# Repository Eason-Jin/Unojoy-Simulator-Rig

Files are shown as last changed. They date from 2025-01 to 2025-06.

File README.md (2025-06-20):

# Unojoy-Simulator-Rig

This is a simple [Unojoy](https://github.com/AlanChatham/UnoJoy) controller I configured to play Euro Truck Simulator 2.

## Phase 1

A simple mockup of the controller with some off-the-shelf components, including push buttons, potentiometers, rotary encoders and switches. \
\
A picture of the mockup os shown below:
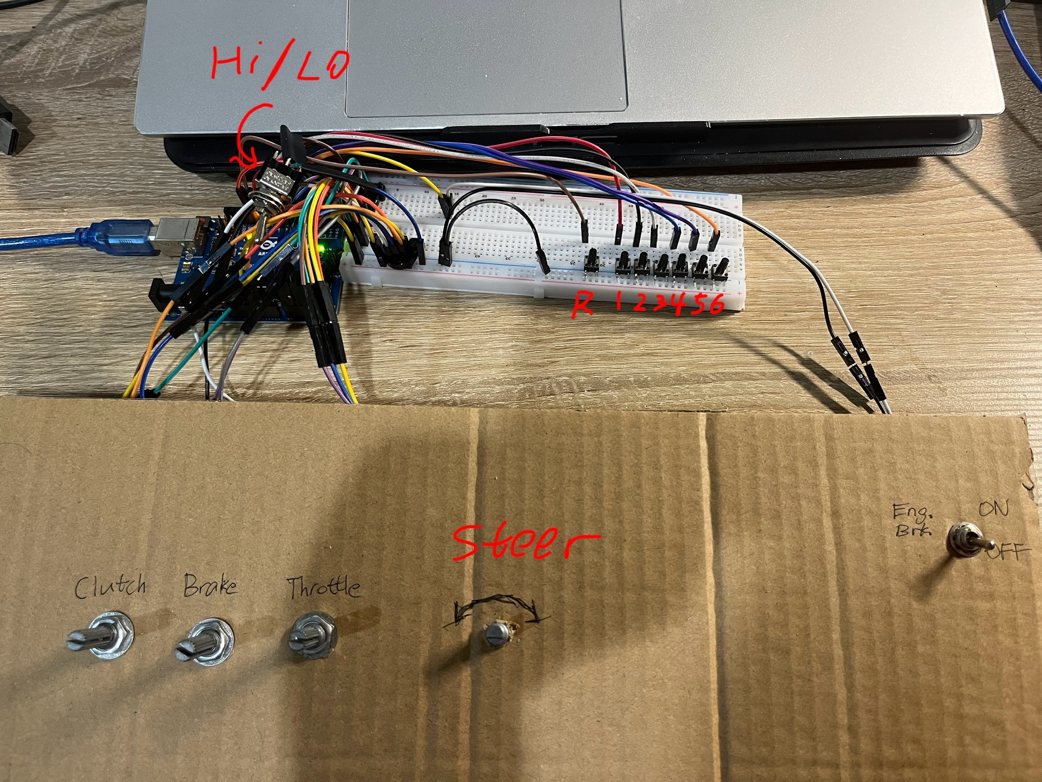
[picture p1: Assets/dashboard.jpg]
Mockup


The configration is as follows:

* 1 [Arduino Uno](https://surplustronics.co.nz/products/7014-arduino-uno-r3-clone-with-usb-cable).
* 1 [rotary encoder](https://surplustronics.co.nz/products/10776-rotary-encoder-module) for the steering wheel.
* 3 [potentiometers](https://surplustronics.co.nz/products/1686-10k-ohm-linear-potentiometer-) for the throttle, brake and clutch. Another one will be added later for the camera.
* 2 [toggle switches](https://surplustronics.co.nz/products/4314-switch-toggle-on-on-spdt-3-pins-panel-mount) as engine brake switch and high-low gear selector.
* 7 [tactile push buttons](https://surplustronics.co.nz/products/2159-switch-tact-push-button-momentary) for 6 forward gears and 1 reverse gear.

The wiring diagram is shown below:
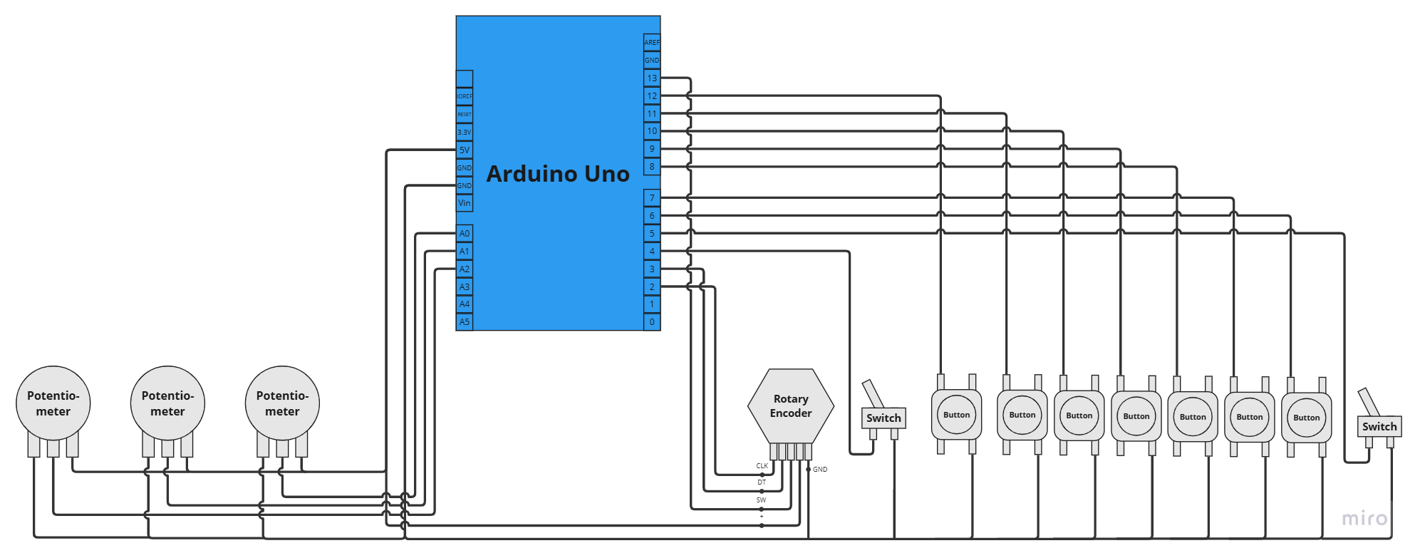
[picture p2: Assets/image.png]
Wiring diagram


Videos of the controller in action are under the `Assets` folder.

Shifting through a 12 speed with only hand controls is hard😅. So in phase 2 I will visit the near by wreckers to salvage some parts.

## Phase 2

### Acquiring Parts

I took the steering wheel out of a Mazda 323 (5th gen, BF). The 3D printed parts will adapt to this particlar steering wheel.

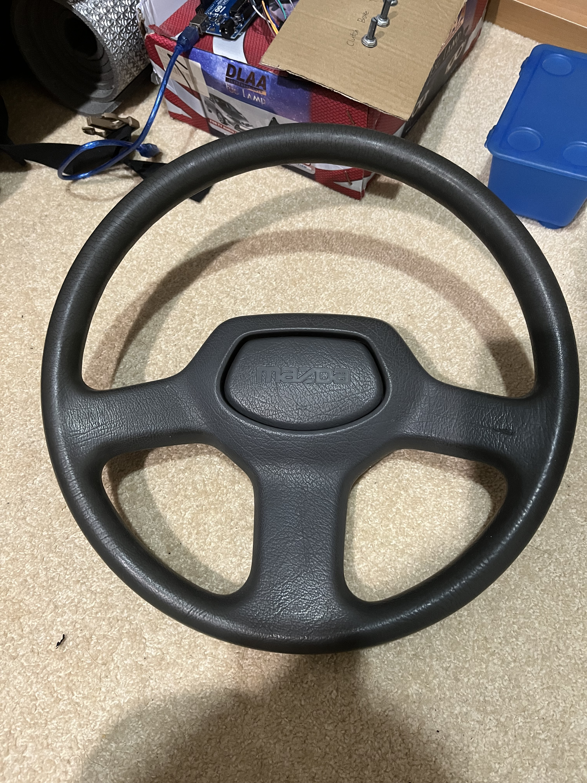
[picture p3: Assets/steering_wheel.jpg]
Steering Wheel


A picture of the car for reference (not this exact car):
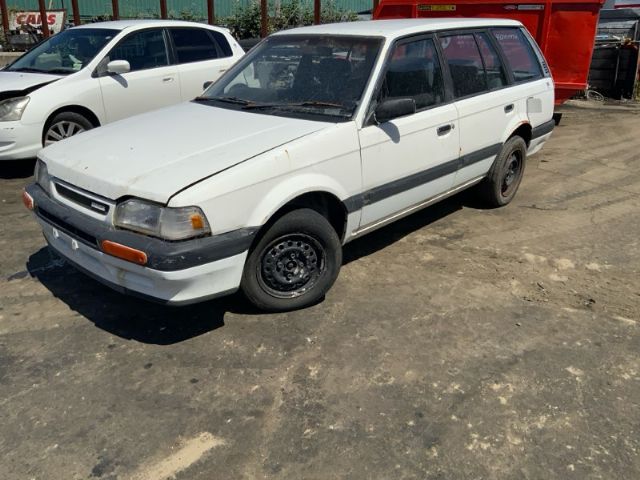
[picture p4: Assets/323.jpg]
Car


The seat is taken from the most luxurious car ever, the pinnicle of Australian engineering, the most beautiful curves human have ever crafted...

The AU Falcon Series II Wagon. (Image for illustration):
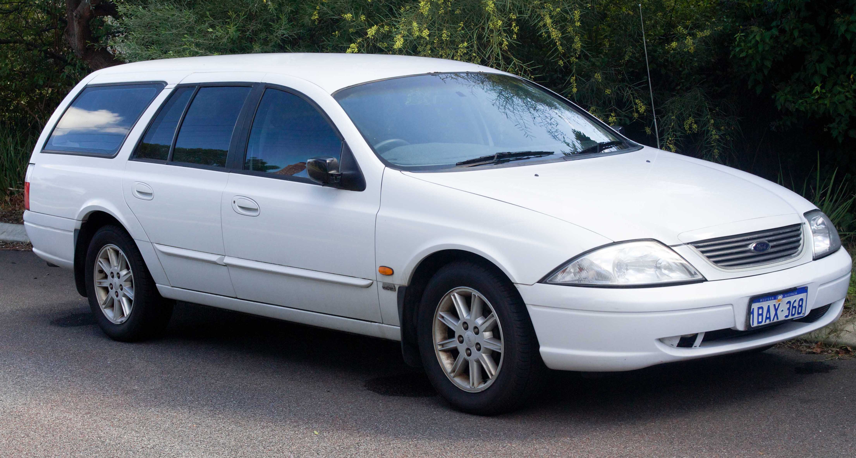
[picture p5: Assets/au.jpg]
AU Falcon


I will be constructing the rest of the simulator using 3D printed parts and off-the-shelf hardware. All CAD files are found under the `CAD` folder. CAD models are made with Autodesk Inventor.

### Steering Assembly

The steering wheel will be sandwiched between the grey and purple parts. The main steering shaft is a 32mm diameter PVC pipe. The steering wheel will be placed in between the silver and pink parts and held using a long M10 bolt for strength.

#### Front view

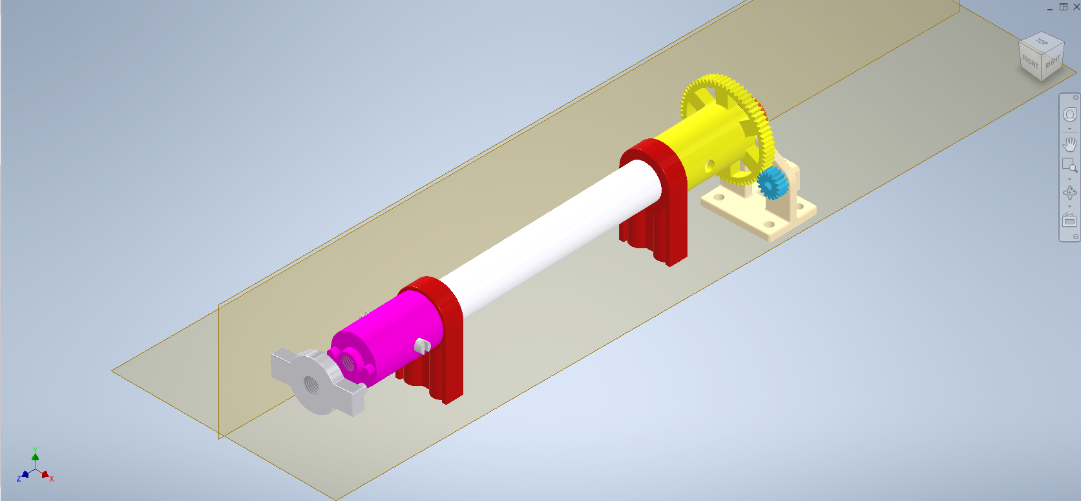
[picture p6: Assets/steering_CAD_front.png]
Steering front


#### Rear view

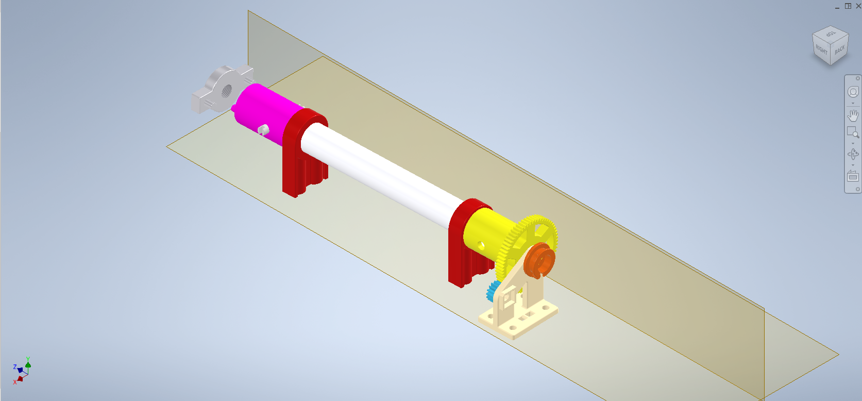
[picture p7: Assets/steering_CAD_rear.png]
Steering rear


A rubber band will be attached to the orange part behind the gear and goes to the support structure. This will provide auto-centering force. A proper force feedback motor is planned for the future.\
\
The cream support structure and the two red posts will be screwed to a wooden base plate with M6 screws.\
\
The encoder is a cheaper product, thus it only has 12 pulses per revolution. To counter that, a set of gears with ratio 16:64 to slightly increase the resolution. The encoder will go into the slot on the back of the cream support.

### Pedal Assembly

The three pedals will be revolving around the same 32mm PVC pipe. There is a hook on the green support and an ear on the grey pedals. A spring will be attached to the hook and the ear to provide resistance and resetting pedal positions. The potentiometers will be attached using a rope drive as shown in this [video](https://www.youtube.com/watch?v=5Pex7cJlhsA&list=WL&index=2&t=226s).

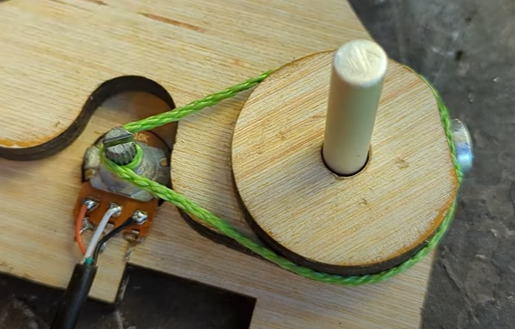
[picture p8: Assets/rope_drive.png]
Rope Drive


#### Front view

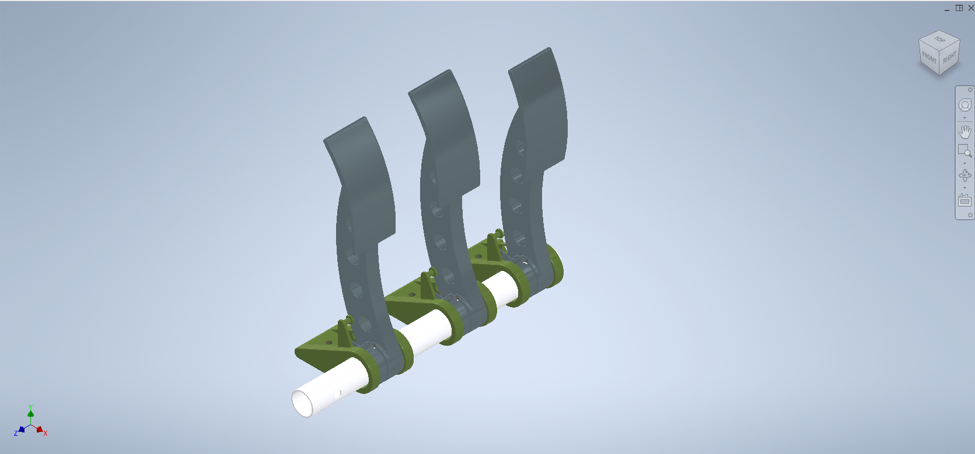
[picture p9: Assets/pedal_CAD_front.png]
Pedal Front


#### Rear view

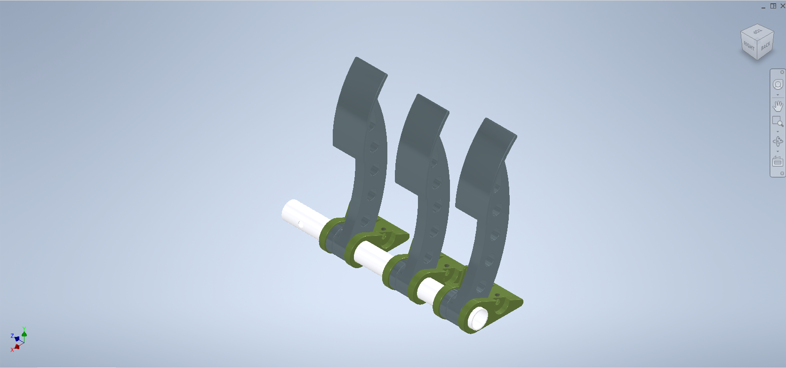
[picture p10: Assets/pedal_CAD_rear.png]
Pedal Rear


#### Pedal movement

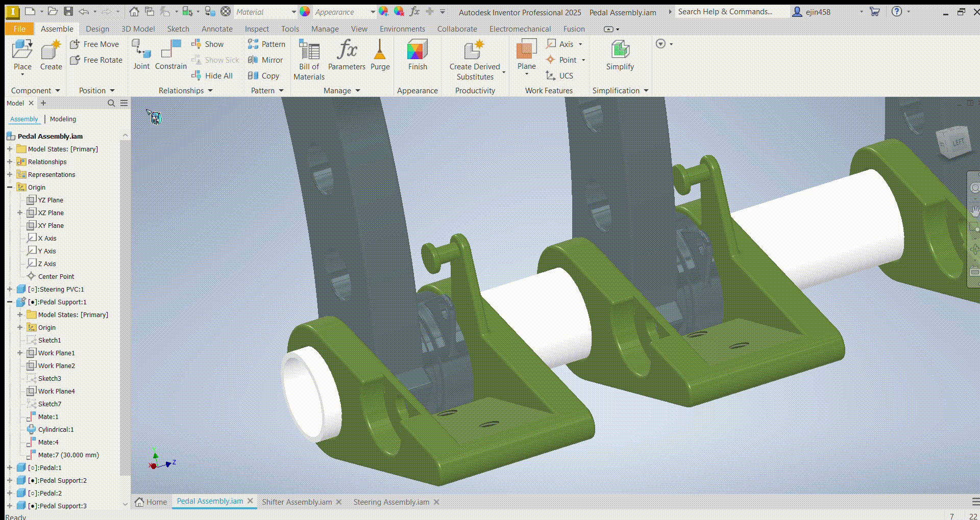
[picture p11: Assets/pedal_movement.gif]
Pedal Movement


Egonomics will be tested on these pedals to ensure comfort and ease of heel-and-toe shifting. The shape and size of the pedals may subject to change. (Or I might get some real pedals from a car, who knows?)

### Shifter Assembly

The shifter is a standard 6-speed H-pattern shifter with reverse next to 1st gear. The supporting columns and the actual shift rod are 15mm PVC pipes. One of the column needs to be removed to leave space for the reverse. However, considering they have very little load on them, this will not affect the stability of the shifter.

#### Front view

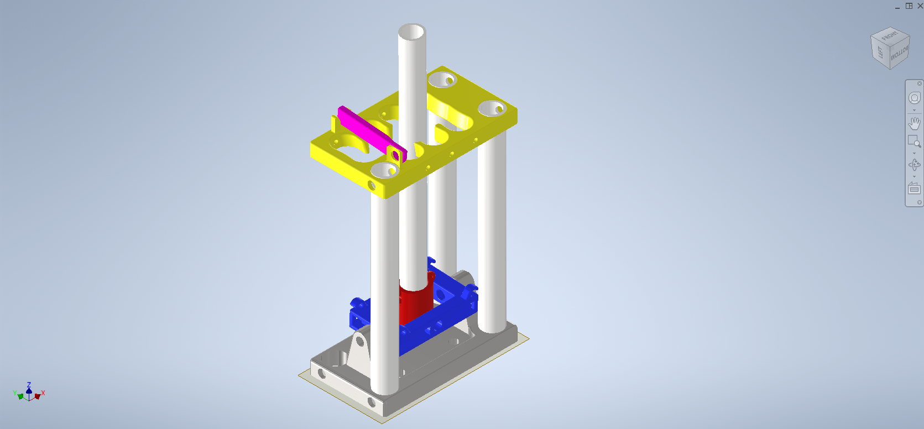
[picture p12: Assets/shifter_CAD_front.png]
Shifter Front


#### Rear view

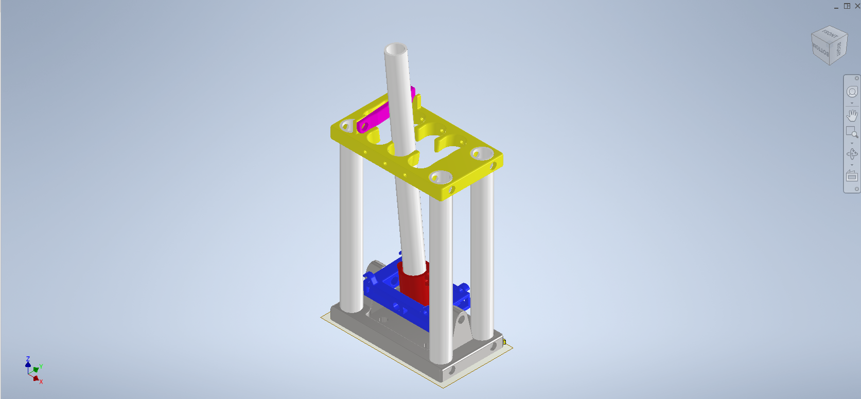
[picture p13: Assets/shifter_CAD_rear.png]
Shifter Rear


The purple piece is the reverse lockout, which can be flipped up for the shifter to move into reverse. This is inspired by the shifter in the [Ferrari 312 T2](https://www.youtube.com/watch?v=Ag03SegGTds). Jkjk 😁

| | |
| --- | --- |
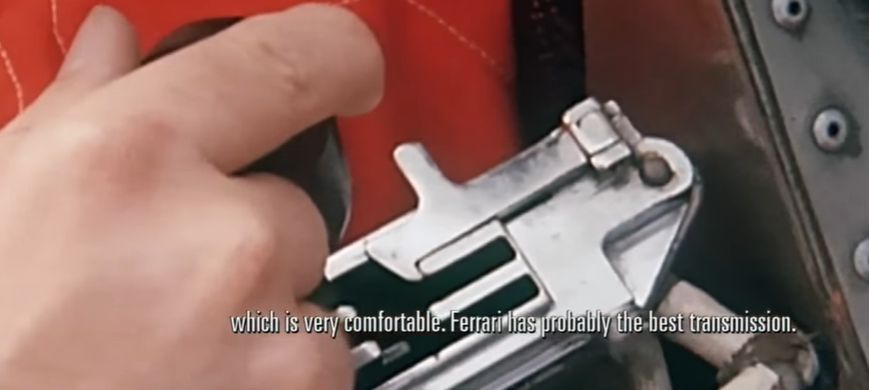
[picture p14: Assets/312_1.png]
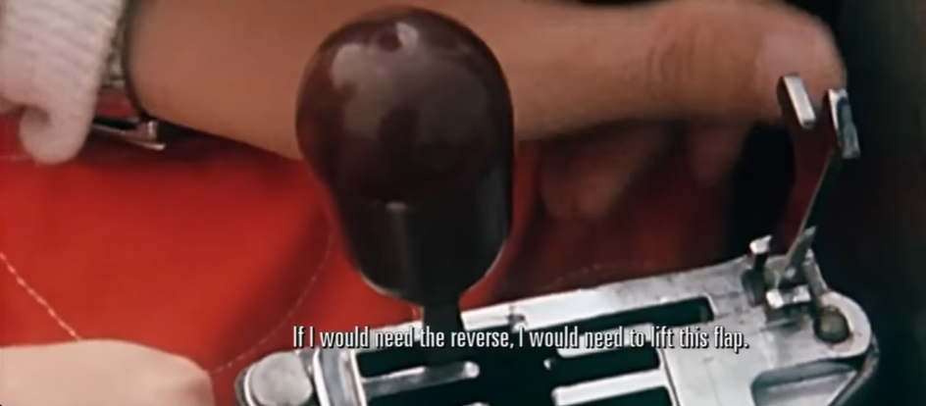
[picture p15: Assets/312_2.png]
|  |  |

#### Top view

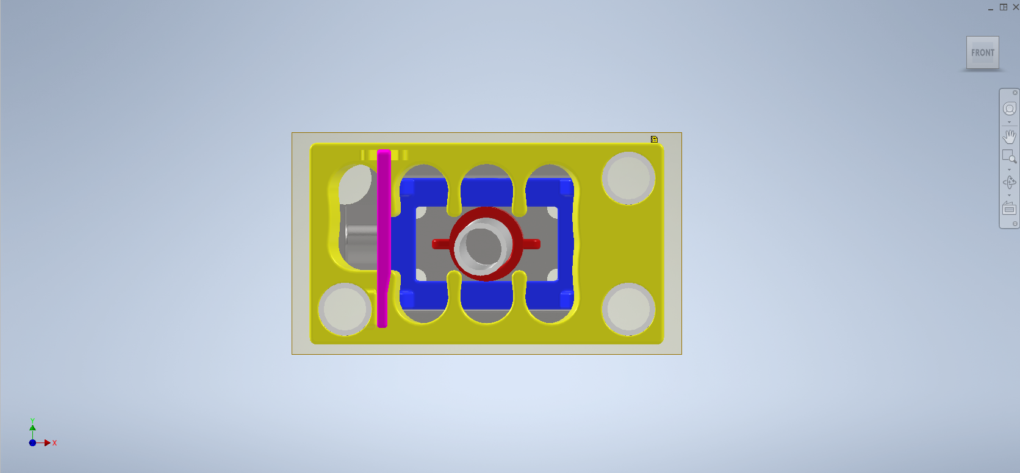
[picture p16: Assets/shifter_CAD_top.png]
Shifter Top


The tabs on the red part and the blue hooks are, again, for rubber bands for auto-centering horizontally (we keep this project low-budget💸). The slots that the shifter go in have a slightly narrow entrance, this allows the shifter to "pop" in place and stay there. \
\
There are holes on the side walls for the wire to run through. Another wire will run along the shift rod, when it moves into position, the wires will contact and complete the ciruit.

#### Shifter movement

Shifter Movement

Considering the amount of connections needed for shifter and gear knob alone, I might migrate some of the inputs to a second Arduino. This will also allow for more buttons and switches to be added in the future.

### Shift Knob

The shift knob is divided into 3 sections. The blue part has a switch poking out of it as the high/low range selector. The Orange part has a joystick to allow rotation of the camera. The grey part contains the potentiometer for the joystick.

#### Front view

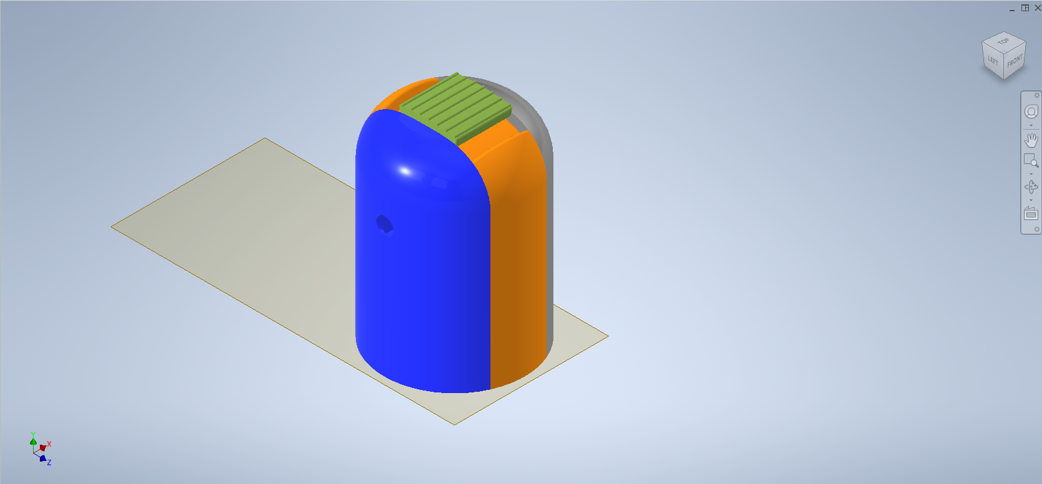
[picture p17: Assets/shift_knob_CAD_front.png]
Knob Front


#### Rear view

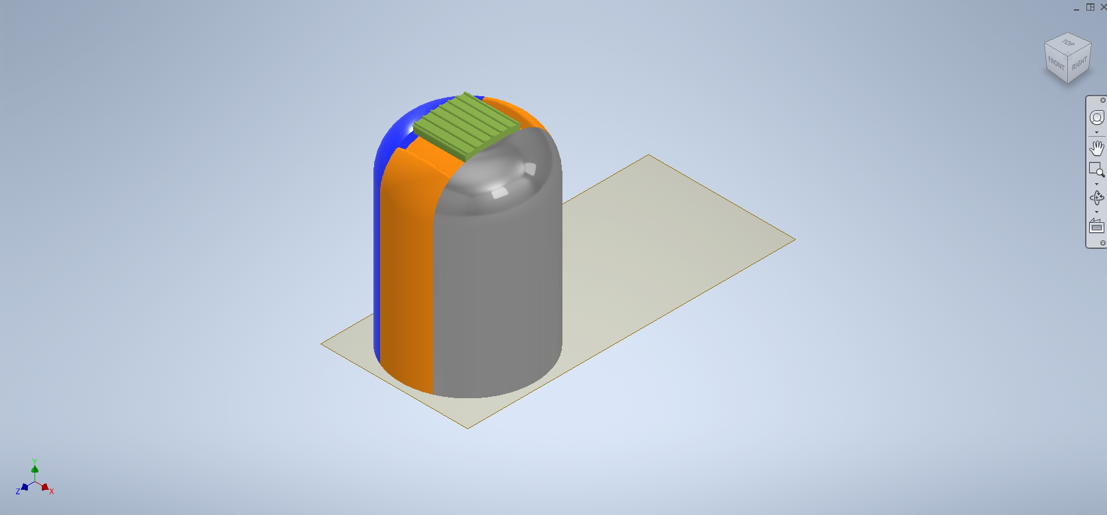
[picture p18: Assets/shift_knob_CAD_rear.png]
Knob Rear


#### Bottom view

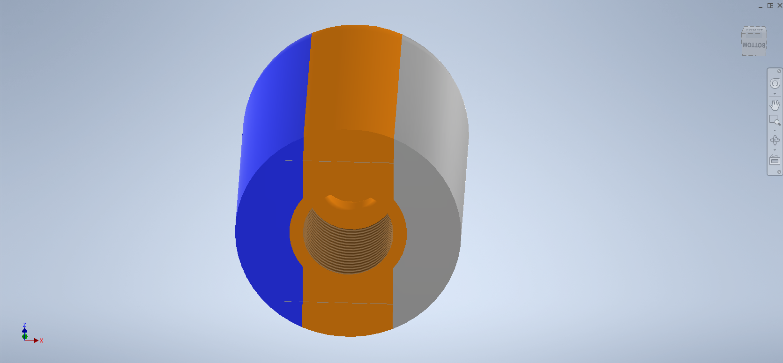
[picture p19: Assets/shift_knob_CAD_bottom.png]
Knob Bottom


The bottom of the shift knob is a M20 thread with a 12mm hole for the wires to run through.

#### Knob details

Knob Details

The joystick has a tab at the bottom, which allows rubber band to be attached on either side for auto-centering the camera. Due to the nature of Euro Trucks gameplay, vertical camera movement is not important.

## Phase 3

Various improvements were made along the way to the CAD models. Such as:

* The steering assembly was flipped upside-down so that it can be mounted on a angle without it being too high.
* The auto-centering rubber band was omitted because the wheel is simply too heavy for it to do anything (this issue should be solved with the introduction of a force-feedback motor in the future).
* The reverse lockout was omitted due to the lack of space.
* The pedals were shortened and mounted upside-down for a more natural feel.

Here are some angles of the complete construction:

| | |
| --- | --- |
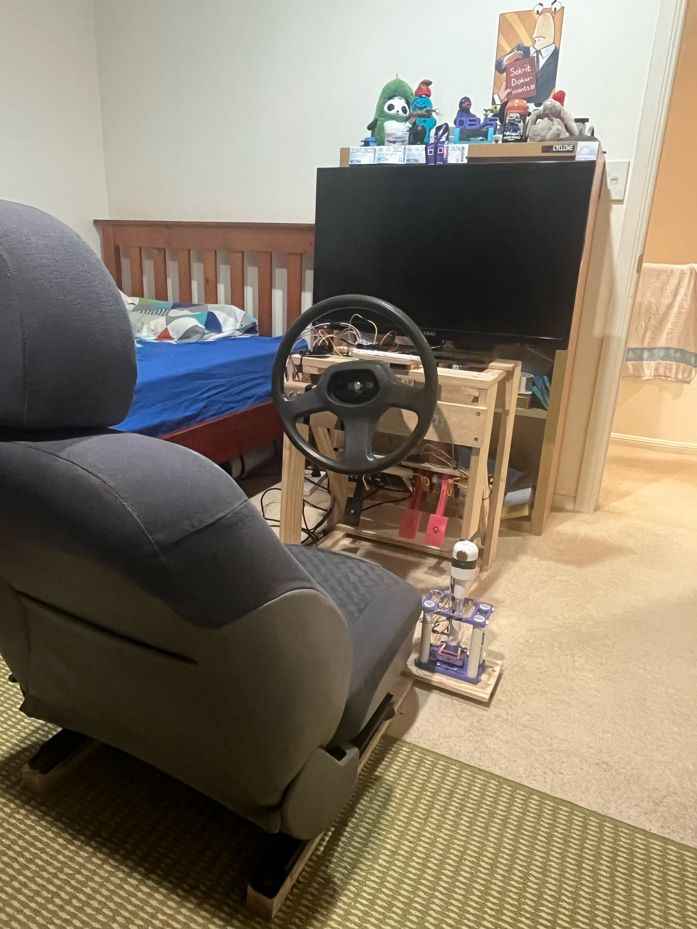
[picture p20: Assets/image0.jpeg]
Full
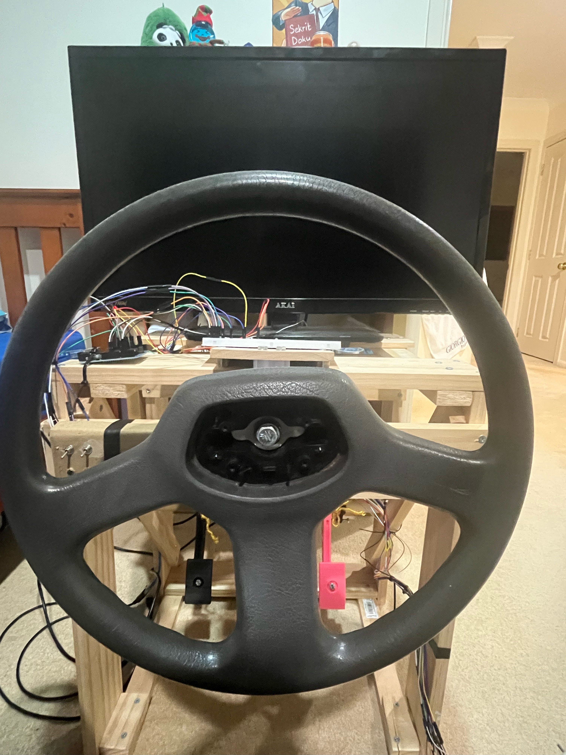
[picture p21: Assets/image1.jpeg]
Steering
|  |  |
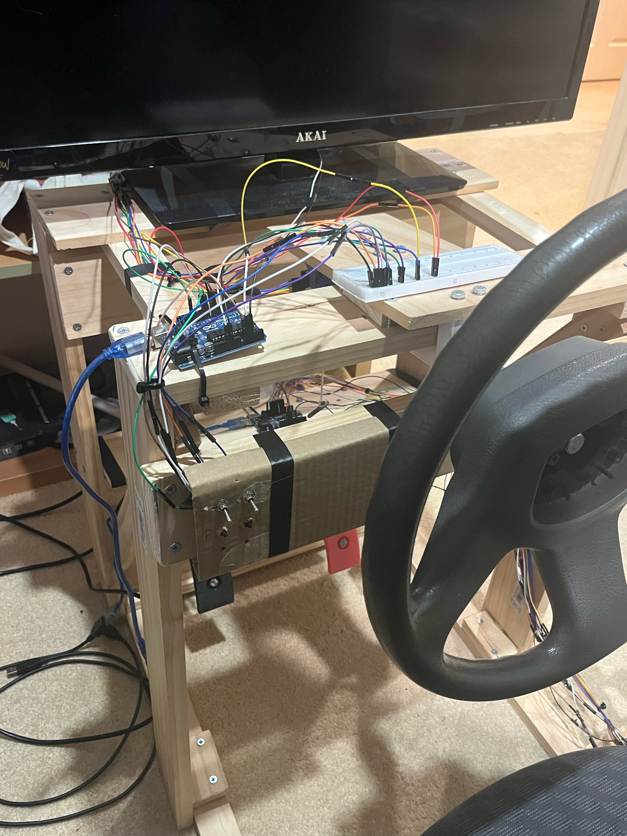
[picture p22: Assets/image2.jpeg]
Steering board
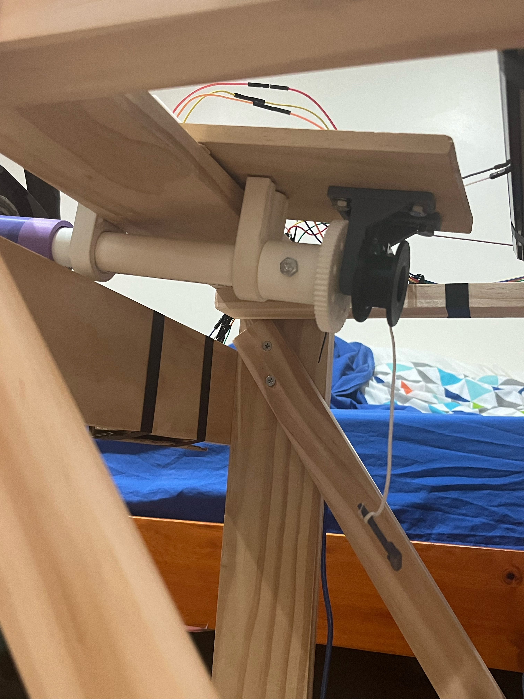
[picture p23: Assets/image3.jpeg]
Steering connection
|  |  |
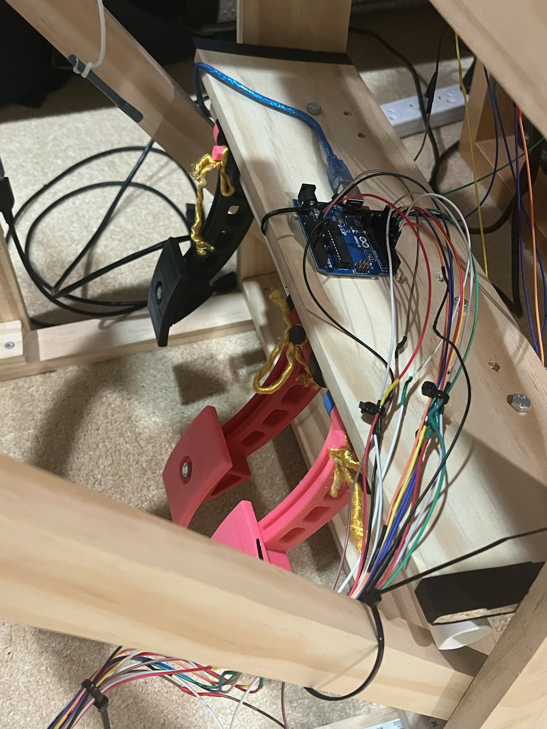
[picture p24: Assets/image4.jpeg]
Pedals
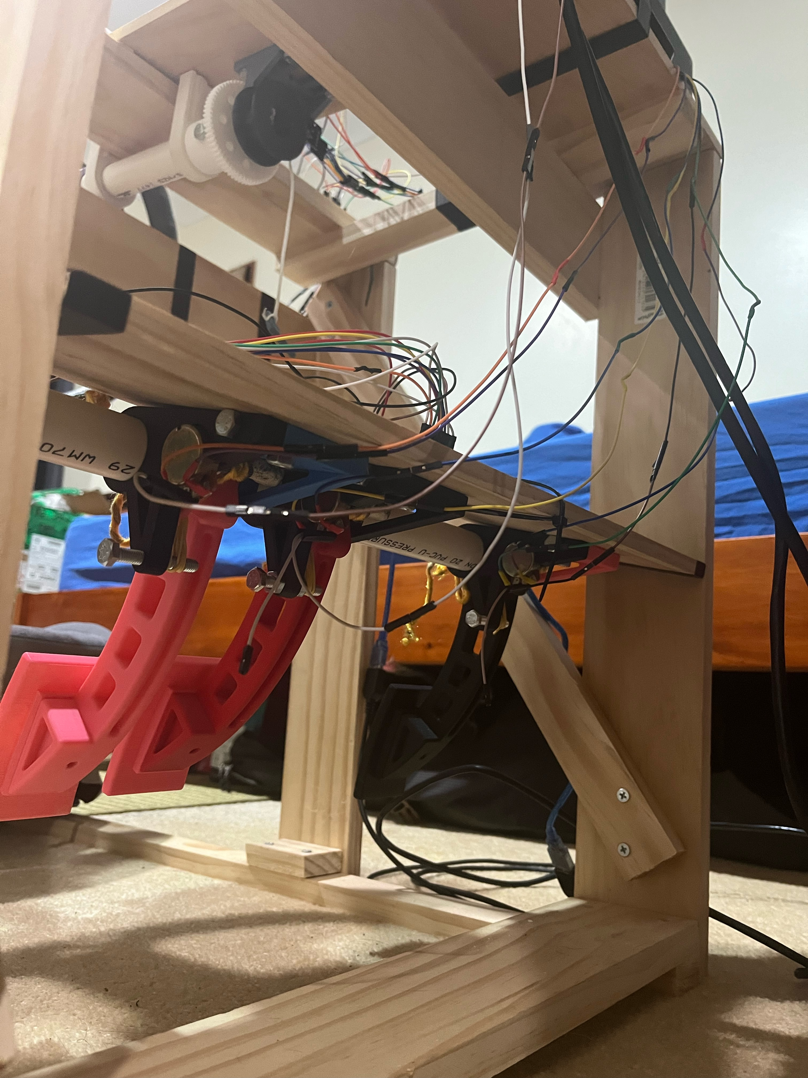
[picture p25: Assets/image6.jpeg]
Pedals back
|  |  |
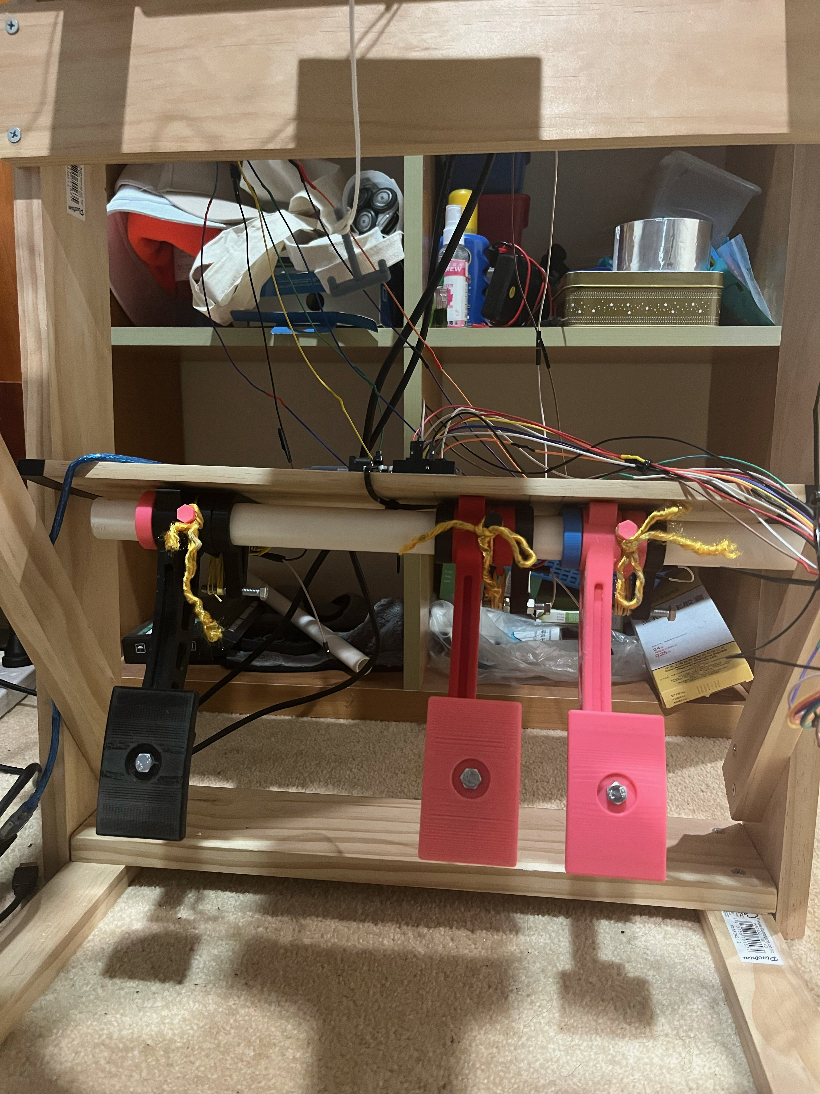
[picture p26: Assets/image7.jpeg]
Pedals front
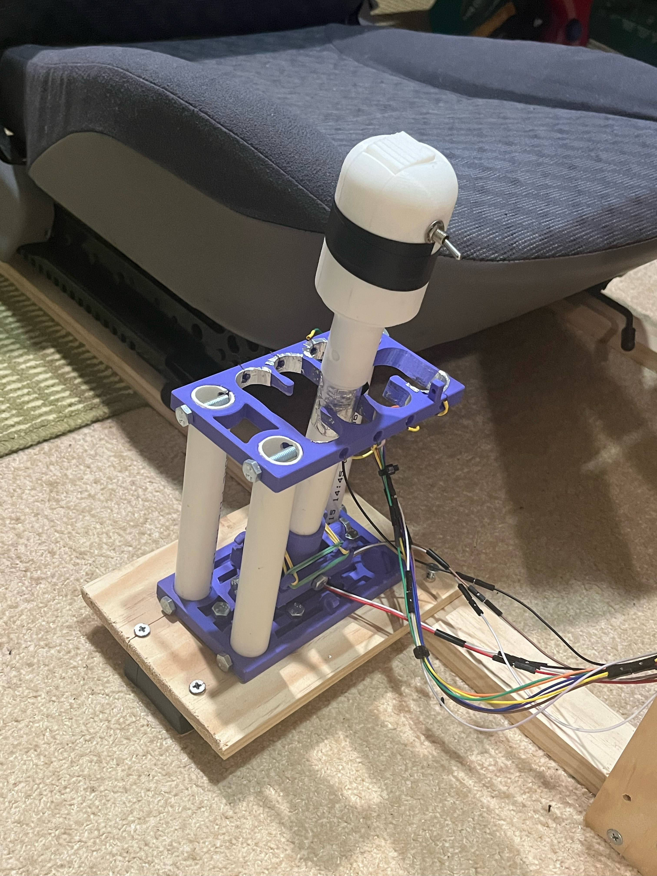
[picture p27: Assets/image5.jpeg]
Shifter
|  |  |

### Demostration

Short video

Or, watch the full video on [YouTube](https://youtu.be/UTyCCYQ6A6k).

## Acknowledgements

* Thanks to my friend Oscar for helping me constructing this abomination.
* Thanks to my host family for trusting me that I am not making a bomb when they saw the questionable wiring and electronics.
* Thanks to my local Bunnings and Pick-a-Part for the materials (not sponsored).

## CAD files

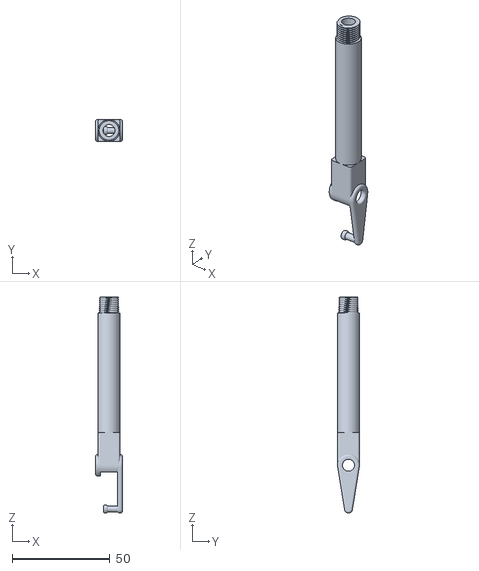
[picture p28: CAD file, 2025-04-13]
CAD/Indicator/STL Files/Stalk.stl
13.8 x 11.2 x 110.7

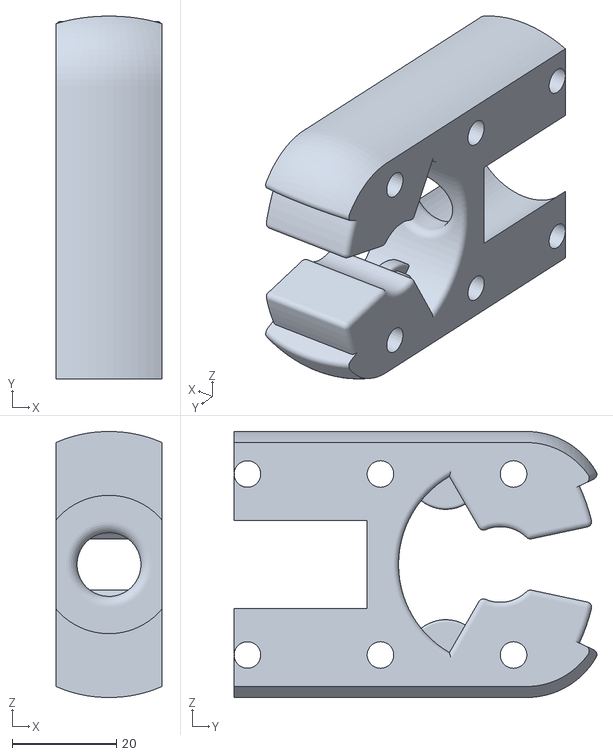
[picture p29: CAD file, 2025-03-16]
CAD/Shift Knob/STL Files/Middle.stl
20.4 x 69.5 x 51.0

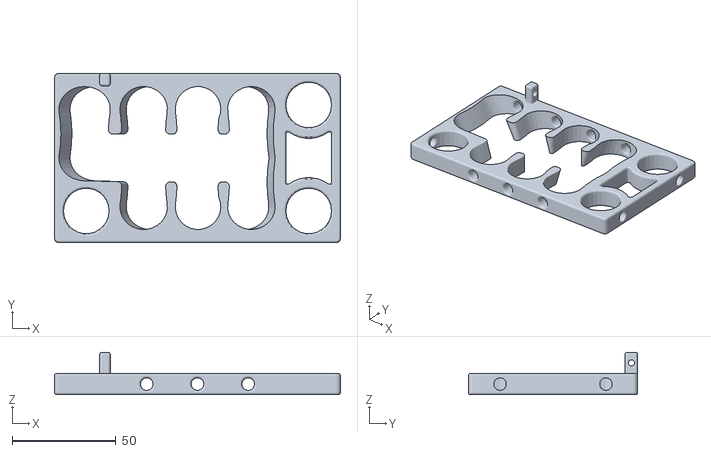
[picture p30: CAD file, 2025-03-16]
CAD/Shifter/STL Files/Shifter Gater.stl
137.7 x 81.6 x 20.4

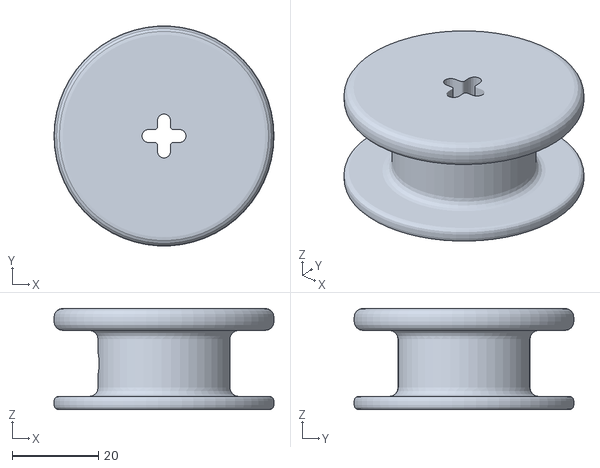
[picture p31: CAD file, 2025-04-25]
CAD/Steering/STL Files/Steering Gear Plate.stl
51.0 x 50.9 x 23.5

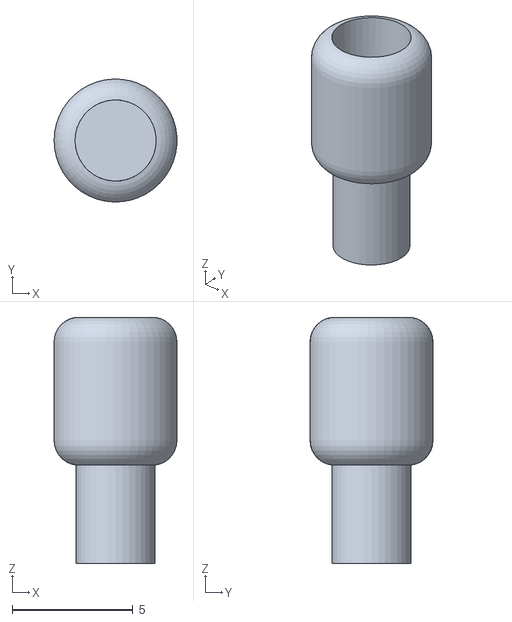
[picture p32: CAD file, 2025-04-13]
CAD/Indicator/STL Files/Hat.stl
5.09 x 5.10 x 10.2

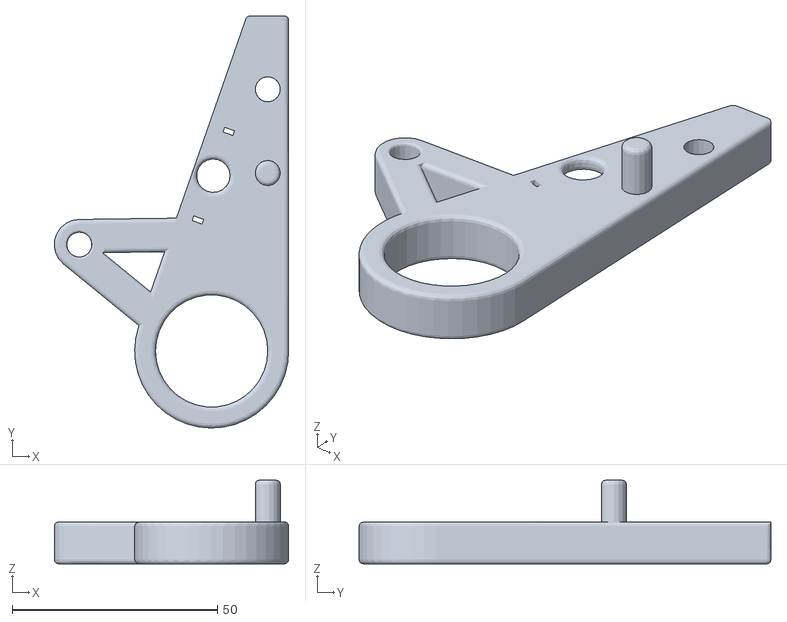
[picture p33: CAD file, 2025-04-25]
CAD/Pedals/STL Files/Pedal Support L.stl
57.1 x 100.4 x 20.4

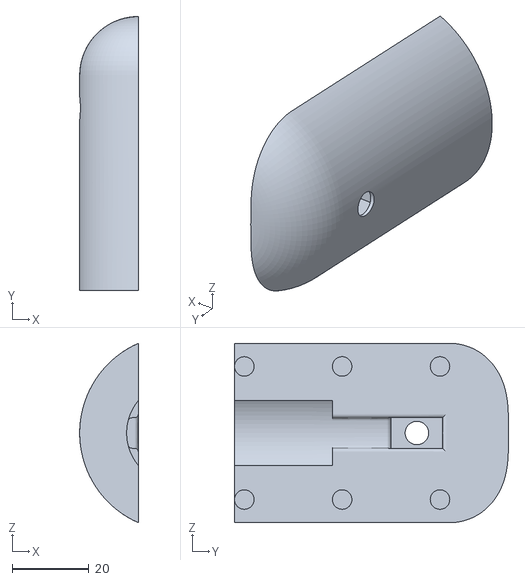
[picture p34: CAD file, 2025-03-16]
CAD/Shift Knob/STL Files/Switch Side.stl
15.3 x 71.4 x 46.7

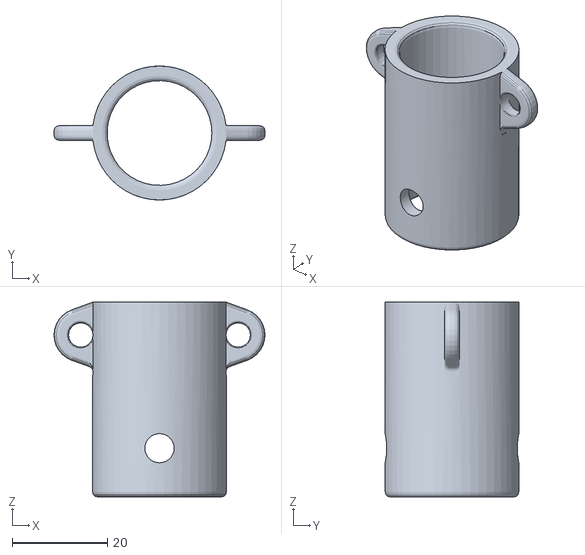
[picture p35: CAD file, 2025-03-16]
CAD/Shifter/STL Files/Shifter Joint.stl
44.2 x 28.1 x 40.8

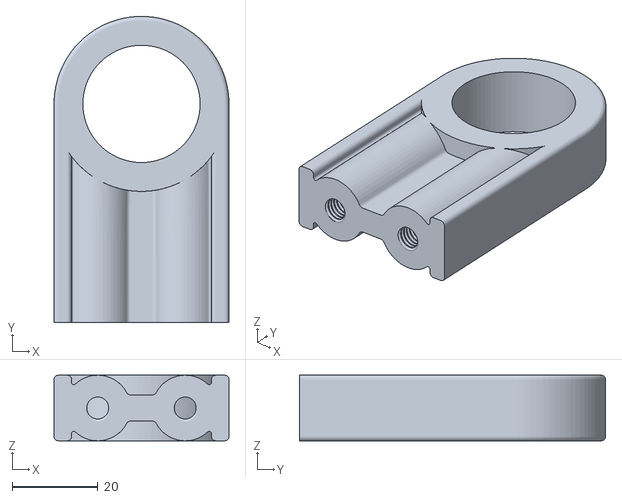
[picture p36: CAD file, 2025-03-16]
CAD/Steering/STL Files/Steering Support.stl
40.8 x 71.4 x 15.3

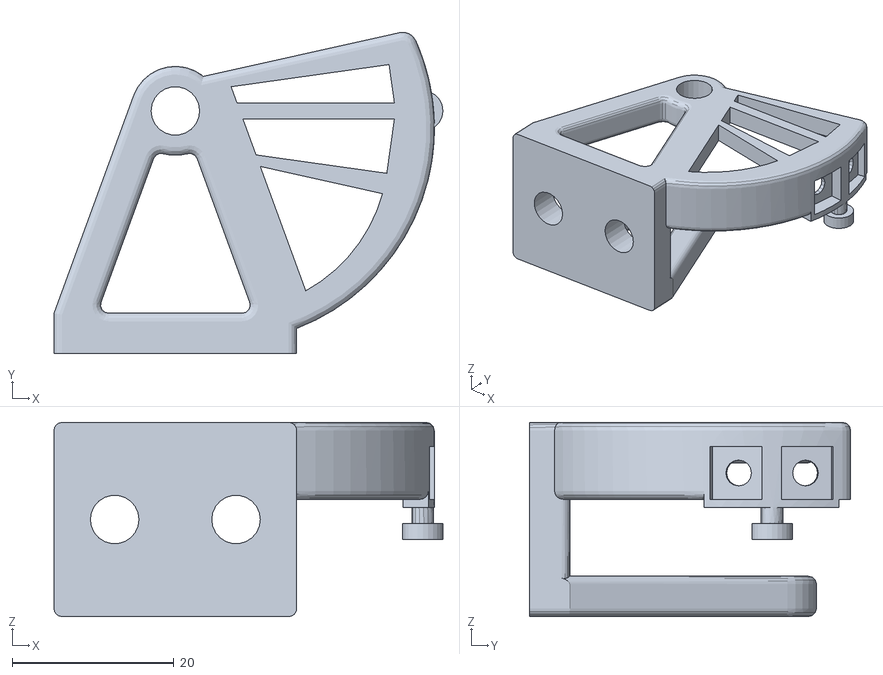
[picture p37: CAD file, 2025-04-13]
CAD/Indicator/STL Files/Stand.stl
48.1 x 39.7 x 24.0

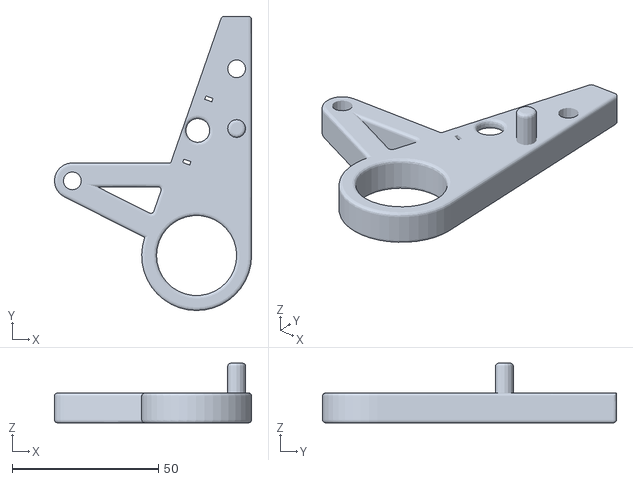
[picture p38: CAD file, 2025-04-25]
CAD/Pedals/STL Files/Pedal Support L New.stl
67.3 x 100.4 x 20.4

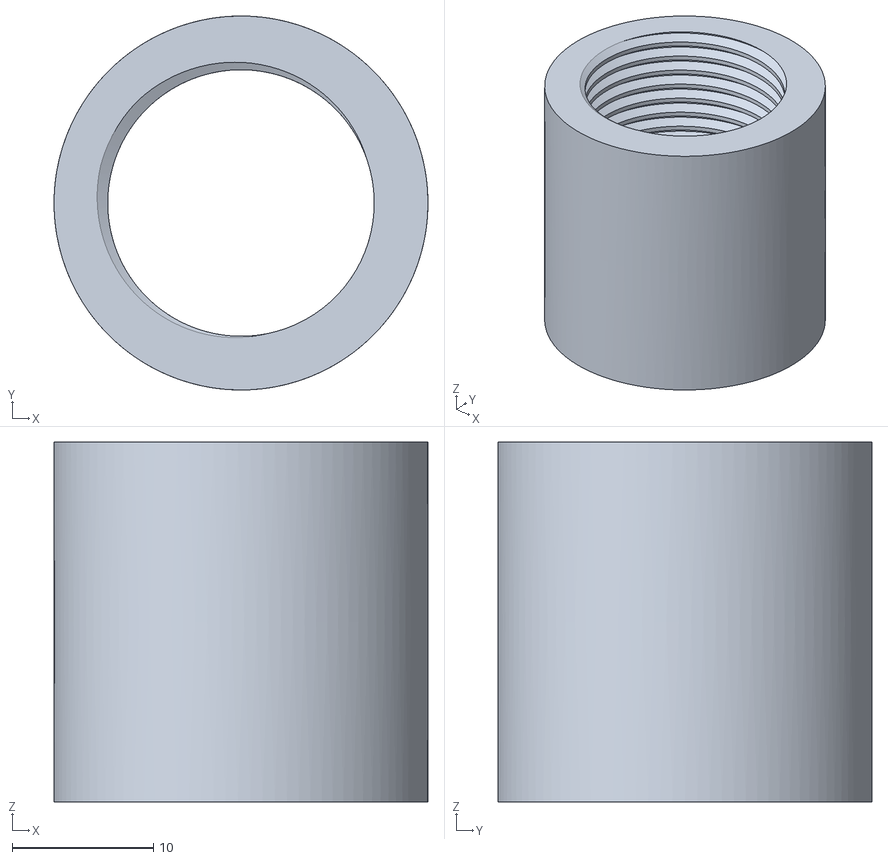
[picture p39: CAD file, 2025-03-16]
CAD/Shift Knob/STL Files/Middle Thread.stl
26.5 x 26.5 x 25.5

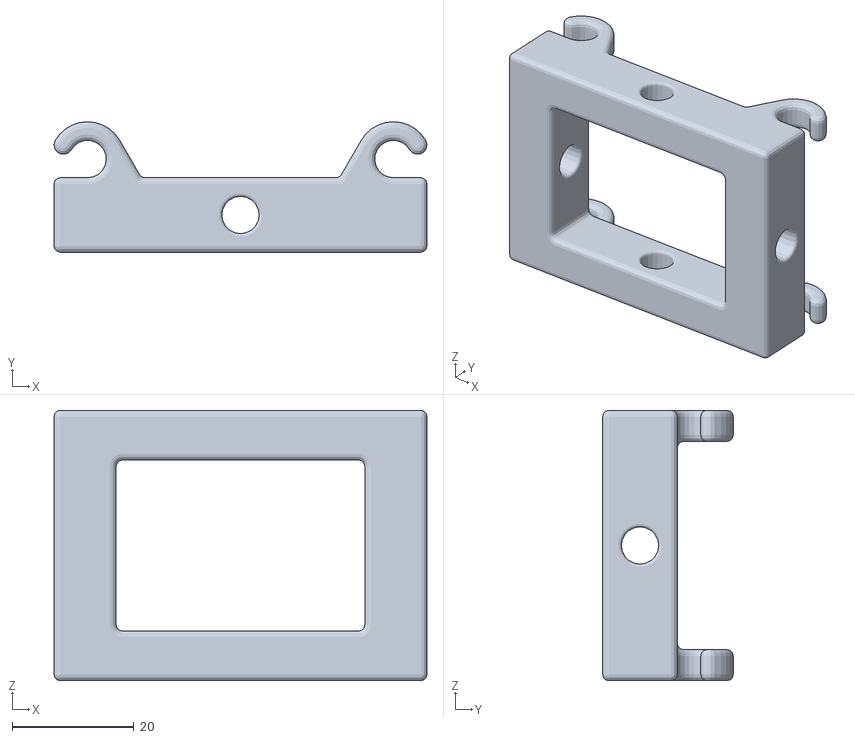
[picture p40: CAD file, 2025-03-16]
CAD/Shifter/STL Files/Shifter Joint 2.stl
61.2 x 21.4 x 44.4

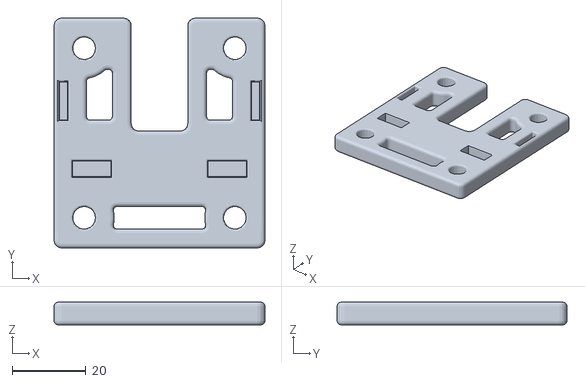
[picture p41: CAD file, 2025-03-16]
CAD/Steering/STL Files/Steering Mounting Plate 2.stl
57.1 x 62.2 x 6.12

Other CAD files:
CAD/Indicator/STL Files/Rod.stl
CAD/Pedals/STL Files/Pedal Face Short.stl
CAD/Shift Knob/STL Files/Adapter.stl
CAD/Shifter/STL Files/Shifter Support.stl
CAD/Indicator/Button.ipt
CAD/Indicator/Hat.ipt
CAD/Indicator/Indicator Assembly.iam
CAD/Indicator/Rod.ipt
CAD/Indicator/Stalk.ipt
CAD/Indicator/Stand.ipt
CAD/Pedals/Pedal Arm Short.ipt
CAD/Pedals/Pedal Arm.ipt
CAD/Pedals/Pedal Assembly.iam
CAD/Pedals/Pedal Face Short.ipt
CAD/Pedals/Pedal Face.ipt
CAD/Pedals/Pedal Support Base.ipt
CAD/Pedals/Pedal Support L New.ipt
CAD/Pedals/Pedal Support L.ipt
CAD/Pedals/Pedal Support R.ipt
CAD/Pedals/STL Files/Pedal 1.stl
CAD/Pedals/STL Files/Pedal 2.stl
CAD/Pedals/STL Files/Pedal Arm Short.stl
CAD/Pedals/STL Files/Pedal Support 1.stl
CAD/Pedals/STL Files/Pedal Support R.stl
CAD/Pedals/STL Files/Screw.stl
CAD/Pedals/Screw.ipt
CAD/Pedals/Steering PVC.ipt
CAD/Shift Knob/Adapter.ipt
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

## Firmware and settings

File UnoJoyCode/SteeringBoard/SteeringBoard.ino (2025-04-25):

#include "UnoJoy.h"

#define CLK 2  // Clock pin
#define DT 3   // Data pin
#define SW 13  // Button pin (not used)

#define POT1 A0  // Left Y potentiometer
#define POT2 A1  // Right Y potentiometer
#define POT3 A2  // Right X potentiometer

#define RANGE 800

int leftStickX = 128;   // Start in the middle (0-255 range)
int leftStickY = 128;   // Start in the middle (0-255 range)
int rightStickX = 128;  // Start in the middle (0-255 range)
int rightStickY = 128;  // Start in the middle (0-255 range)

// Variables for the rotary encoder
volatile int lastEncoded = 0;
volatile long encoderValue = 0;
volatile int lastMSB = 0;
volatile int lastLSB = 0;

int readPedal(int pin) {
    float reading = map(analogRead(pin), 0, 1023, 0, 255) * 2;
    return constrain(reading, 0, 255);
}

void setup() {
  setupPins();
  setupUnoJoy();
  
  // Set up rotary encoder pins
  pinMode(CLK, INPUT_PULLUP);
  pinMode(DT, INPUT_PULLUP);
  
  // Attach interrupts for rotary encoder
  attachInterrupt(digitalPinToInterrupt(CLK), updateEncoder, CHANGE);
  attachInterrupt(digitalPinToInterrupt(DT), updateEncoder, CHANGE);
  
  // Initialize lastEncoded value
  lastEncoded = (digitalRead(CLK) << 1) | digitalRead(DT);
}

void loop() {
  dataForController_t controllerData = getControllerData();
  
  // Convert encoder value to leftStickX (steering)
  // Map the encoder value to the joystick range
  leftStickX = map(encoderValue, -RANGE, RANGE, -255, 255);

  // Assign mapped values to controllerData
  controllerData.leftStickX = leftStickX;    // Steering
  controllerData.leftStickY = readPedal(POT1);
  controllerData.rightStickX = readPedal(POT2);
  controllerData.rightStickY = readPedal(POT3);

  // Send controller data
  setControllerData(controllerData);
  delay(5);
}

void updateEncoder() {
  int MSB = digitalRead(CLK);  // Most significant bit
  int LSB = digitalRead(DT);   // Least significant bit
  
  int encoded = (MSB << 1) | LSB;          // Converting the 2 pin values to a single number
  int sum = (lastEncoded << 2) | encoded;  // Adding it to the previous encoded value
  
  // Update encoder value based on the rotation
  if (sum == 0b1101 || sum == 0b0100 || sum == 0b0010 || sum == 0b1011) {
    encoderValue--;  // Clockwise rotation
  }
  if (sum == 0b1110 || sum == 0b0111 || sum == 0b0001 || sum == 0b1000) {
    encoderValue++;  // Counter-clockwise rotation
  }
  
  // Limit the encoder value to prevent overflow
  encoderValue = constrain(encoderValue, -RANGE, RANGE);
  
  // Store the encoded value for next time
  lastEncoded = encoded;
}

void setupPins(void) {
  for (int i = 4; i <= 13; i++) {
    pinMode(i, INPUT);
    digitalWrite(i, HIGH);
  }

  pinMode(A4, INPUT);
  digitalWrite(A4, HIGH);
  pinMode(A5, INPUT);
  digitalWrite(A5, HIGH);
}

dataForController_t getControllerData(void) {
  dataForController_t controllerData = getBlankDataForController();
  controllerData.crossOn = !digitalRead(6);
  controllerData.circleOn = !digitalRead(7);
  controllerData.squareOn = !digitalRead(8);
  controllerData.triangleOn = !digitalRead(9);

  return controllerData;
}

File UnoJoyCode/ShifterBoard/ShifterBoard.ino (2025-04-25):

#include "UnoJoy.h"

#define POT1 A0 // Camera

int leftStickX = 128; 

void setup() {
  setupPins();
  setupUnoJoy();
}

void loop() {
  dataForController_t controllerData = getControllerData();

  // Send controller data
  setControllerData(controllerData);
  delay(5);
}

void setupPins(void) {
  for (int i = 4; i <= 13; i++) {
    pinMode(i, INPUT);
    digitalWrite(i, HIGH);
  }

  pinMode(A4, INPUT);
  digitalWrite(A4, HIGH);
  pinMode(A5, INPUT);
  digitalWrite(A5, HIGH);
}

dataForController_t getControllerData(void) {
  dataForController_t controllerData = getBlankDataForController();
  controllerData.circleOn = digitalRead(5);    // Gear splitter
  controllerData.l1On = !digitalRead(6);        // 1st
  controllerData.l2On = !digitalRead(7);        // 2nd
  controllerData.l3On = !digitalRead(8);        // 3rd
  controllerData.r1On = !digitalRead(9);        // 4th
  controllerData.r2On = !digitalRead(10);       // 5th
  controllerData.r3On = !digitalRead(11);       // 6th
  controllerData.squareOn = !digitalRead(12);   // Reverse
  return controllerData;
}

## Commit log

2025-02-03 Added CAD files for steering wheel adapter
    [Steering Back.ipt, Steering Front.ipt]
2025-02-04 More CAD
    [Encoder Gear.ipt, Steering Gear.ipt, Steering Mounting Plate.ipt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]
2025-02-06 Steering CAD
    [Encoder Gear.ipt, Gear Test.iam, Steering Assembly.iam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]
2025-02-09 Shifter CAD
    [Encoder Gear.ipt, Gear Test.iam, Locating Pin.ipt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]
2025-02-15 More CAD and updated README
    [Pedal Assembly.0003.iam, Pedal Assembly.iam, Shifter Assembly.0010.iam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]
2025-02-15 Updated CAD
    [Shifter Assembly.0010.iam, Shifter Assembly.0011.iam, Shifter Assembly.iam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]
2025-02-16 Shifter CAD and update README
    [Base.ipt, Joystick.ipt, Middle.ipt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]
2025-03-16 Updated CAD for printing
    [Adapter.ipt, Adapter.stl, Axle.ipt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]
2025-04-13 deleted oldversion
    [Steering Back.0007.ipt]
2025-04-25 finishing touches
    [Pedal Support L New.ipt, Pedal Support L New.stl, Pedal Support L.ipt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]
